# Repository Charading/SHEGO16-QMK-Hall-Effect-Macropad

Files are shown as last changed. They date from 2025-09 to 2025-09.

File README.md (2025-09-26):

# SHEGO16-QMK-Hall-Effect-Macropad
An RP2040-powered 4x4 15 key macropad with a knob on the top row, that runs custom QMK firmware that allows analogue hall effect sensors to work, also has SOCD, works with VIA and SignalRGB
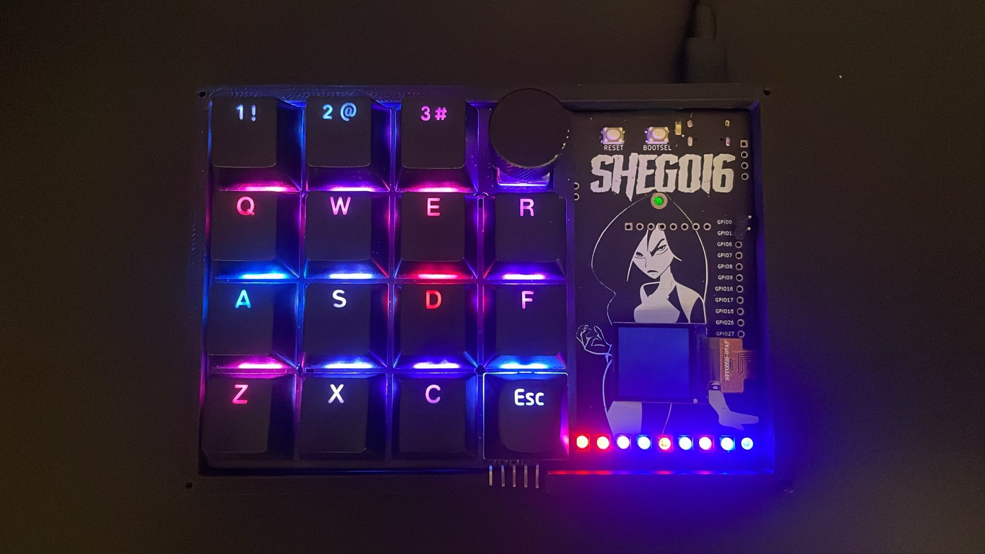
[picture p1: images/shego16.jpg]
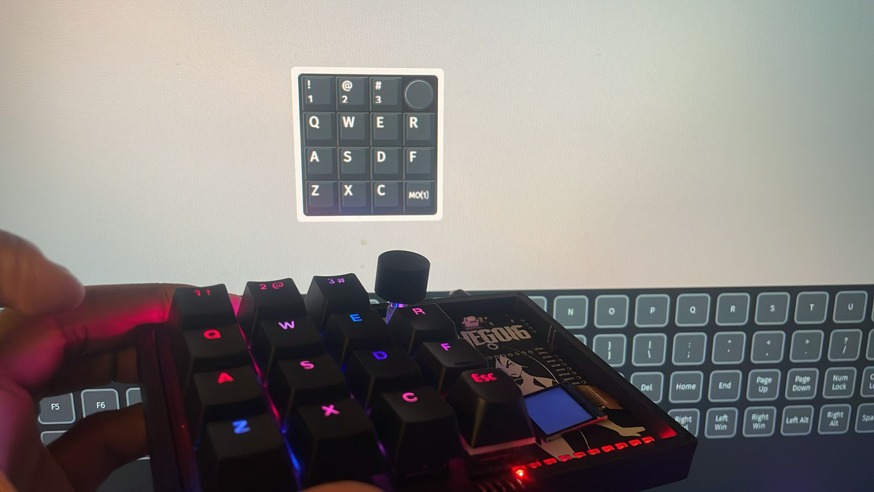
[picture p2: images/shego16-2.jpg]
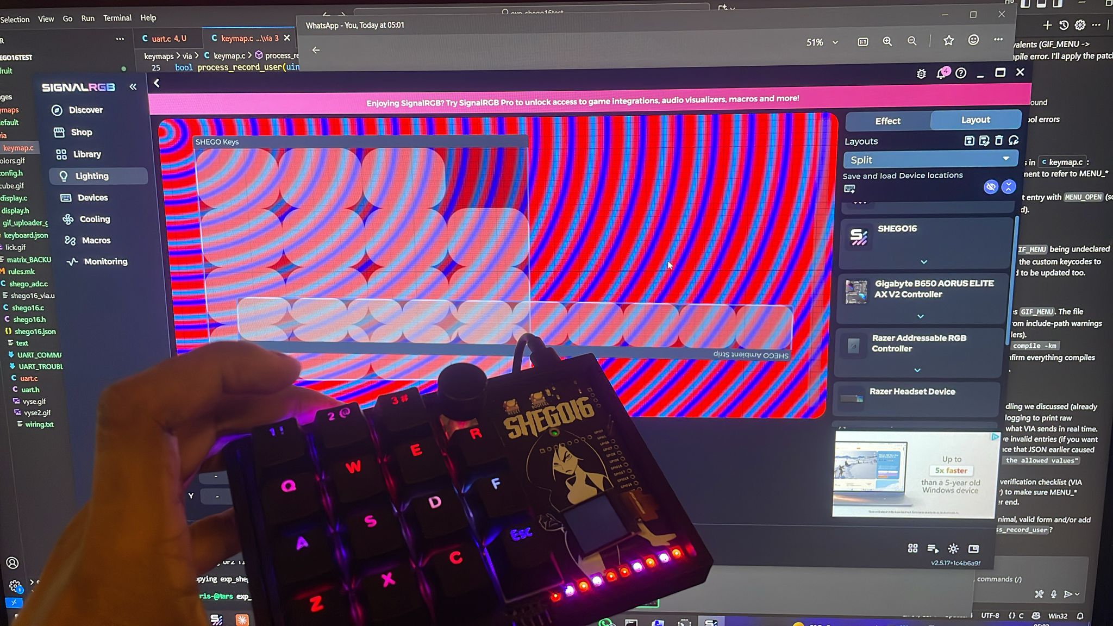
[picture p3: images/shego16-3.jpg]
  

### Features
- QMK Firmware
- VIA Compatible
- Hall effect (adjustable actuation also)
- SOCD (last input wins on A and D)
- Works with SignalRGB
- ST7735 TFT Screen *(currently disabled/broken due to complications and implementing another way)*
- Per-key RGB
- Ambient strip
- Custom keycodes to send to UART to control esp32 *(for tft screen on my future build)* etc
- Multiple GPIO broken out for testing purposes
- Blink LED on GPIO25

I cant find a Hall effect keyboard that i genuinely like that has all the features that i want so i thought to make one myself. Technically i am still in prototype phase for the 'endgame' board i yearn to have, this was a originally a little test board that I was making so I could figure out how to do firmware. I've been working months on end on this project with many pcbs and components surrounding me. The end goal is a 75% keyboard, knob, a tft screen that can play gifs, **north** facing RGB (my goodness i hate south facing), and magnetic switches with socd. Sadly I think it would be too difficult to create a software/web utility to control certain features of the board so thats why after weeks on end trying to build firmware from scratch with C, then scrapped that and tried Rust, then scrapped again and thought to use heavily edited qmk, i am now here.
For my big 75%, the screen will now be implemented by using an [ESP32 running a GIF decoder](https://github.com/Charading/ESP32-GIF-Player ) that accepts UART commands and it uses SD card for storage

Thankyou [riskable](https://github.com/riskable)  for your amazing resources and being my inspiration for this passion project. 

This was one of my first ever pcbs
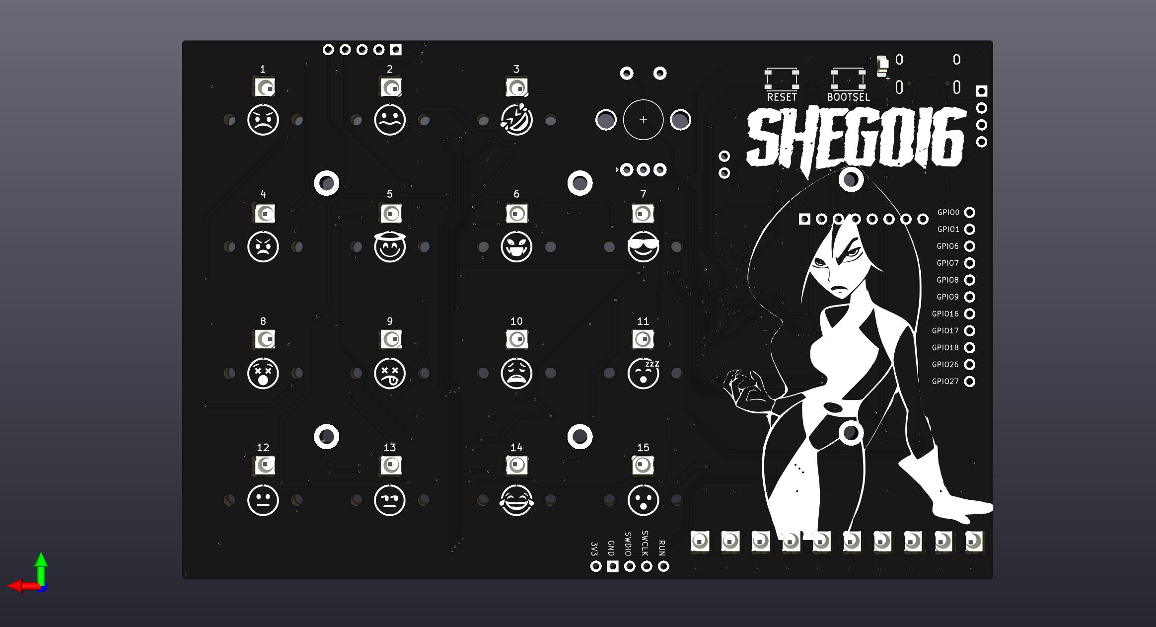
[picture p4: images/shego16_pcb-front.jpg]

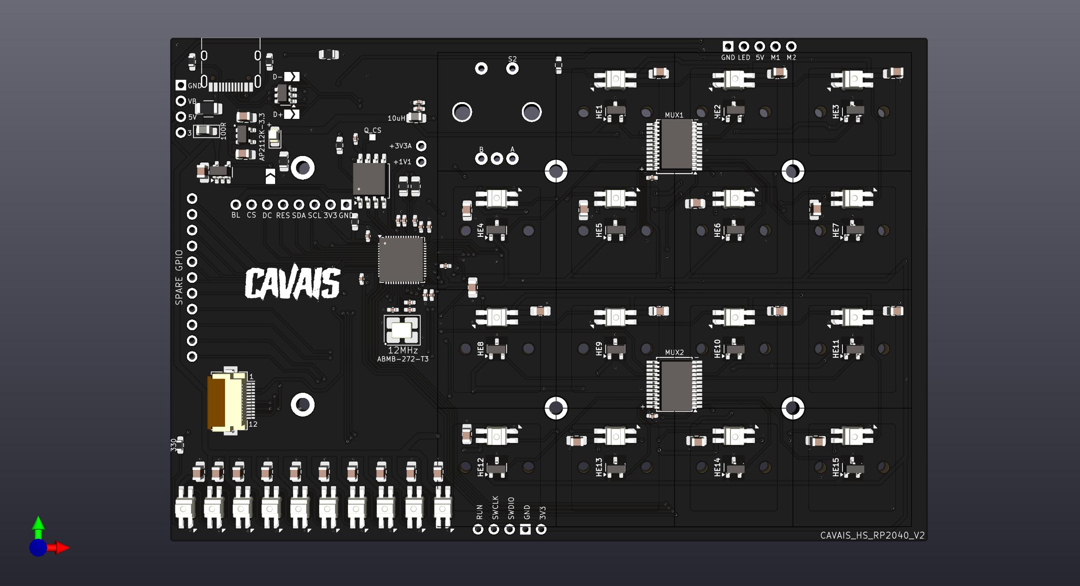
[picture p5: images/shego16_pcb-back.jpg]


I recommend using [this version](https://github.com/Charading/qmk_picosdk
) of qmk for easy building of firmware, i could not get pico/stdlib.h to be located at all with normal qmk_firmware :(.

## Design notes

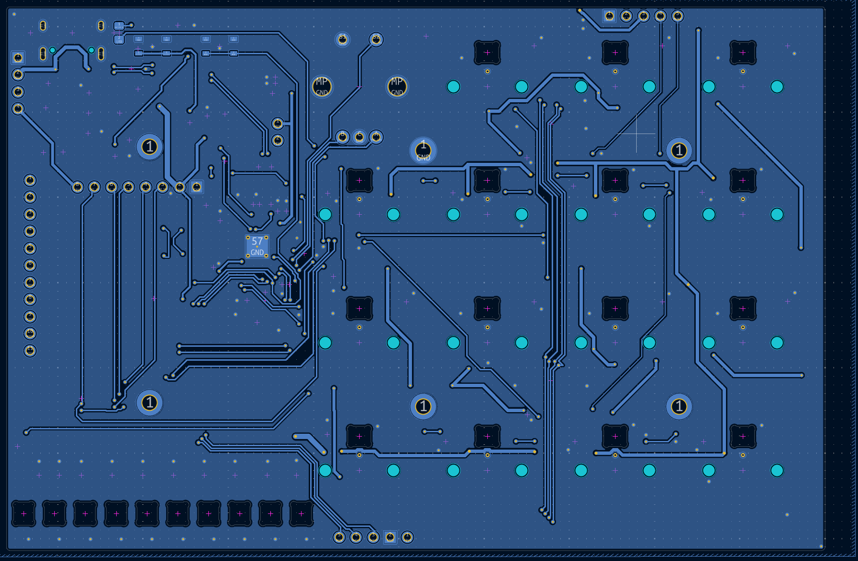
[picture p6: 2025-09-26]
images/pcb-B_Cu.png

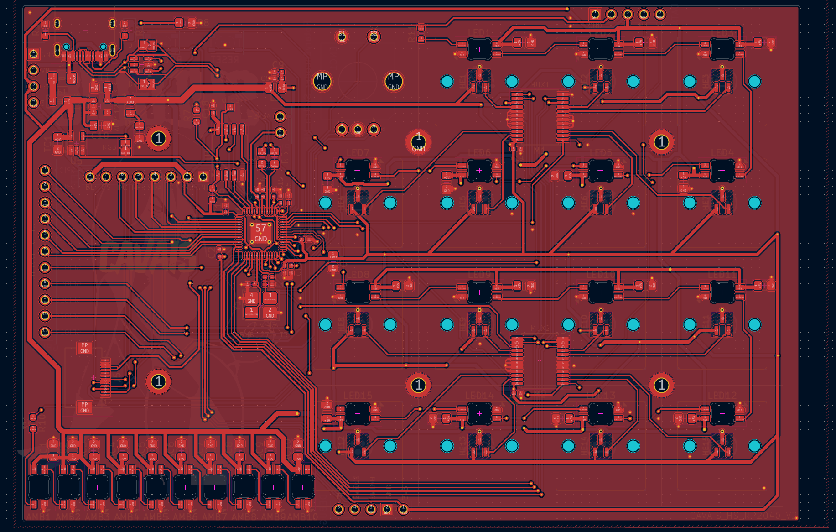
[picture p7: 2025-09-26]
images/pcb-F_Cu.png

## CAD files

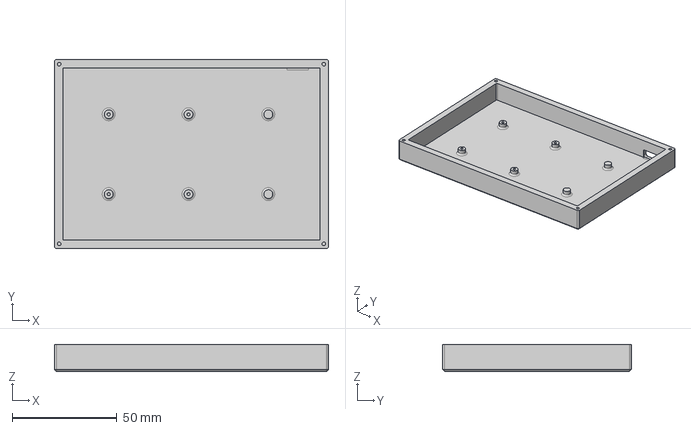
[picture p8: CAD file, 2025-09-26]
shego16-kicad/Cav16 Case v11.step
130.8 x 90.2 x 13.0 mm

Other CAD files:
shego16-kicad/Cav16 Case v9.step

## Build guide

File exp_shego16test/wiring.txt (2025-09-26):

//SPI control pins
#define SPI_SCL GP2
#define SPI_SDA GP3
#define SPI_RES GP4
#define SPI_DC GP5
#define SPI_CS GP24

// MUX control pins
#define MUX_S0 GP10
#define MUX_S1 GP11
#define MUX_S2 GP12
#define MUX_S3 GP13

// MUX enable pins (active low)
#define MUX1_EN GP14
#define MUX2_EN GP15

// ADC pins for reading mux outputs
#define MUX1_ADC_PIN GP29
#define MUX2_ADC_PIN GP28

// Hall effect threshold
#define HALL_THRESHOLD 350

// Mux to sensor wiring, every unused channel is GND. Mux is HC4067, sensors are SS49E.
/*
MUX1 
i0 he2
i1 he3
i6 he7
i7 he6
i8 he5
i9 he4
i15 he1

MUX2
i0 he10
i1 he11
i6 he15
i7 he14
i8 he13
i9 he12
i14 he8
i15 he9
*/

const uint16_t key_thresholds[32] = {
    // MUX1 thresholds
    380, 360, 0, 0, 0, 0, 375, 380, 399, 399, 0, 0, 0, 0, 0, 380,  // E key (ch8) gets 320
    // MUX2 thresholds  
    340, 400, 0, 0, 0, 0, 330, 390, 380, 410, 0, 0, 0, 0, 366, 460
};

Okay, so, is there a way to instead of using a static threshold, to make it so the keyboard scans all adc keys when plugged in, and then it only does a key press when the value deviates up OR down 20% away

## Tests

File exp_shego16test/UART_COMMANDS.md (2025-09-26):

# UART Commands Implementation for Shego16test

This document explains the custom UART functionality added to the Shego16test keyboard for communicating with an ESP32 to control GIF playback.

## Overview

The keyboard now has custom keycodes on Layer 3 that send UART commands to an ESP32. The ESP32 can respond to these commands to control a GIF player interface.

## Hardware Configuration

### Wiring
- **QMK Side (RP2040)**: 
  - TX: GP1 → ESP32 RX pin
  - GND: Connect GND between boards

**Note**: Using GP1 for UART TX to avoid conflicts with RGB matrix pins and other peripherals.

### UART Settings
- **Baud Rate**: 115200
- **Data Bits**: 8
- **Stop Bits**: 1
- **Parity**: None

## Layer Layout

### Layer 3 - UART Commands
```
┌─────────┬─────────┬─────────┬───┐
│GIF_MENU │ GIF_UP  │GIF_DOWN │ENC│
├─────────┼─────────┼─────────┼───┤
│GIF_SELECT│  ---   │   ---   │---│
├─────────┼─────────┼─────────┼───┤
│   ---   │   ---   │   ---   │---│
├─────────┼─────────┼─────────┼───┤
│   ---   │   ---   │   ---   │---│
└─────────┴─────────┴─────────┴───┘
```

## Custom Keycodes

| Keycode | UART Command Sent | Description |
|---|---|---|
| `GIF_MENU` | `MENU_OPEN\n` | Opens/toggles the GIF selection menu |
| `GIF_UP` | `MENU_UP\n` | Navigate up in menu |
| `GIF_DOWN` | `MENU_DOWN\n` | Navigate down in menu |
| `GIF_SELECT` | `MENU_SELECT\n` | Select current GIF |

## Layer Access

To access Layer 3 (UART commands):
- **From Layer 0**: Hold the bottom-right key (was KC_V, now MO(3))
- **From Layer 1**: Hold the bottom-right key (MO(3))

## ESP32 Expected Responses

According to the documentation provided, the ESP32 should send back these responses:

### Status Messages
- `MENU_OPENED` / `MENU_CLOSED` - Menu state changes
- `MENU_POS:3` - Current menu position (number)
- `GIF_SELECTED:filename.gif` - Selected GIF file
- `STATUS:MENU=OPEN,GIF=vyse.gif,POS=2,COUNT=4` - Full status
- `UNKNOWN_COMMAND` - For invalid commands

### How to Test

1. **Build and flash** the firmware to your RP2040
2. **Connect UART wires** between RP2040 and ESP32 as specified
3. **Access Layer 3** by holding the bottom-right key
4. **Press the UART command keys** and monitor the ESP32's serial output
5. **Verify** that the ESP32 receives the expected commands

## Code Files Modified

- `config.h` - Added UART pin definitions
- `rules.mk` - Enabled UART feature
- `keymaps/default/keymap.c` - Added custom keycodes and UART command handling

## Troubleshooting

### No UART Communication
1. Check wiring (TX/RX crossed correctly)
2. Verify baud rate matches on both sides (115200)
3. Ensure GND is connected between boards

### Commands Not Recognized
1. Check that ESP32 code is properly handling the command strings
2. Verify newline characters are being sent (`\n`)
3. Monitor ESP32 serial output for debugging

### Layer 3 Not Accessible
1. Confirm you're holding (not tapping) the MO(3) key
2. Check that the keymap compiled correctly
3. Verify layer switching is working with other layers first

## Future Enhancements

Consider adding:
- Status LED indicators based on ESP32 responses
- Additional UART commands (volume, play/pause, etc.)
- Two-way communication to display ESP32 status on keyboard
- Error handling for failed UART communication

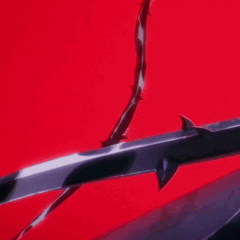
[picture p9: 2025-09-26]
exp_shego16test/vyse2.gif

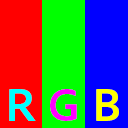
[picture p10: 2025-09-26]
exp_shego16test/colors.gif

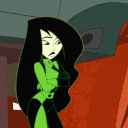
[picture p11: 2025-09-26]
exp_shego16test/gif/init.gif

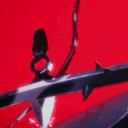
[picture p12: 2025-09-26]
exp_shego16test/vyse.gif

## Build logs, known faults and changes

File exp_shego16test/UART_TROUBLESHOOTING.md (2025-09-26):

# UART Troubleshooting Summary - Shego16test

## What We Implemented
- Custom bit-banged UART implementation on GP1
- UART commands for GIF control (MENU_OPEN, MENU_UP, MENU_DOWN, MENU_SELECT)
- Encoder-based UART controls on Layer 3
- LED feedback to confirm key presses
- Startup test message
- Multiple baud rates tested (115200 and 9600)

## Issues Encountered
- No UART output detected on receiving device
- Custom keycodes trigger (LED feedback works) but UART transmission fails

## Possible Causes
1. **Hardware Issues:**
   - GP1 pin might not be properly connected
   - Voltage level mismatch (3.3V RP2040 vs 5V/different voltage ESP32)
   - Missing ground connection between boards
   - Wrong ESP32 RX pin configuration

2. **Software Issues:**
   - QMK's `wait_us()` function might not be precise enough for bit-banging
   - Interrupt conflicts during transmission
   - Pin configuration conflicts

3. **Timing Issues:**
   - Bit-banged UART timing might be off due to QMK overhead
   - ESP32 might expect different baud rate or timing

## Alternative Approaches to Try Later

### 1. Use QMK's Built-in Serial Driver
```c
// In config.h
#define SERIAL_USART_DRIVER SD1
#define SERIAL_USART_TX_PIN GP0

// In rules.mk
SERIAL_DRIVER = vendor
```

### 2. Use Raw HID Instead of UART
- Send commands via USB HID to host computer
- Host computer forwards to ESP32 via its own UART/USB
- More reliable than bit-banged UART

### 3. Hardware UART (if available)
- Use RP2040's hardware UART peripheral instead of bit-banging
- More precise timing and less CPU overhead

### 4. Different Pin/Voltage Level
- Try different GPIO pin (GP0, GP4, GP8, etc.)
- Add level shifter if voltage mismatch
- Verify ESP32 RX pin with multimeter/oscilloscope

### 5. I2C Communication
- Use I2C protocol instead of UART
- More robust for short-distance communication
- Built-in error checking

## Hardware Debugging Steps
1. **Verify pin output with multimeter:**
   - Check if GP1 goes high/low during transmission
   - Confirm 3.3V levels

2. **Test with simple LED:**
   - Connect LED to GP1 to visually confirm pin toggling
   - Should blink during UART transmission

3. **Check connections:**
   - Verify GP1 → ESP32 RX
   - Verify GND → GND
   - Check for loose connections

## Code Cleanup
If you want to remove UART functionality for now, remove these sections:
- Custom keycodes (GIF_MENU, GIF_UP, GIF_DOWN, GIF_SELECT)
- UART functions (uart_send_byte, uart_send_string)
- UART initialization in keyboard_post_init_user
- UART handling in encoder_update_user and process_record_user

## Current Status
- VIA keymap compiles successfully
- Custom keycodes trigger with LED feedback
- UART transmission implemented but not working
- Ambient LED functionality preserved and working

The implementation is solid from a software perspective - the issue is likely hardware-related or requires a different communication approach.

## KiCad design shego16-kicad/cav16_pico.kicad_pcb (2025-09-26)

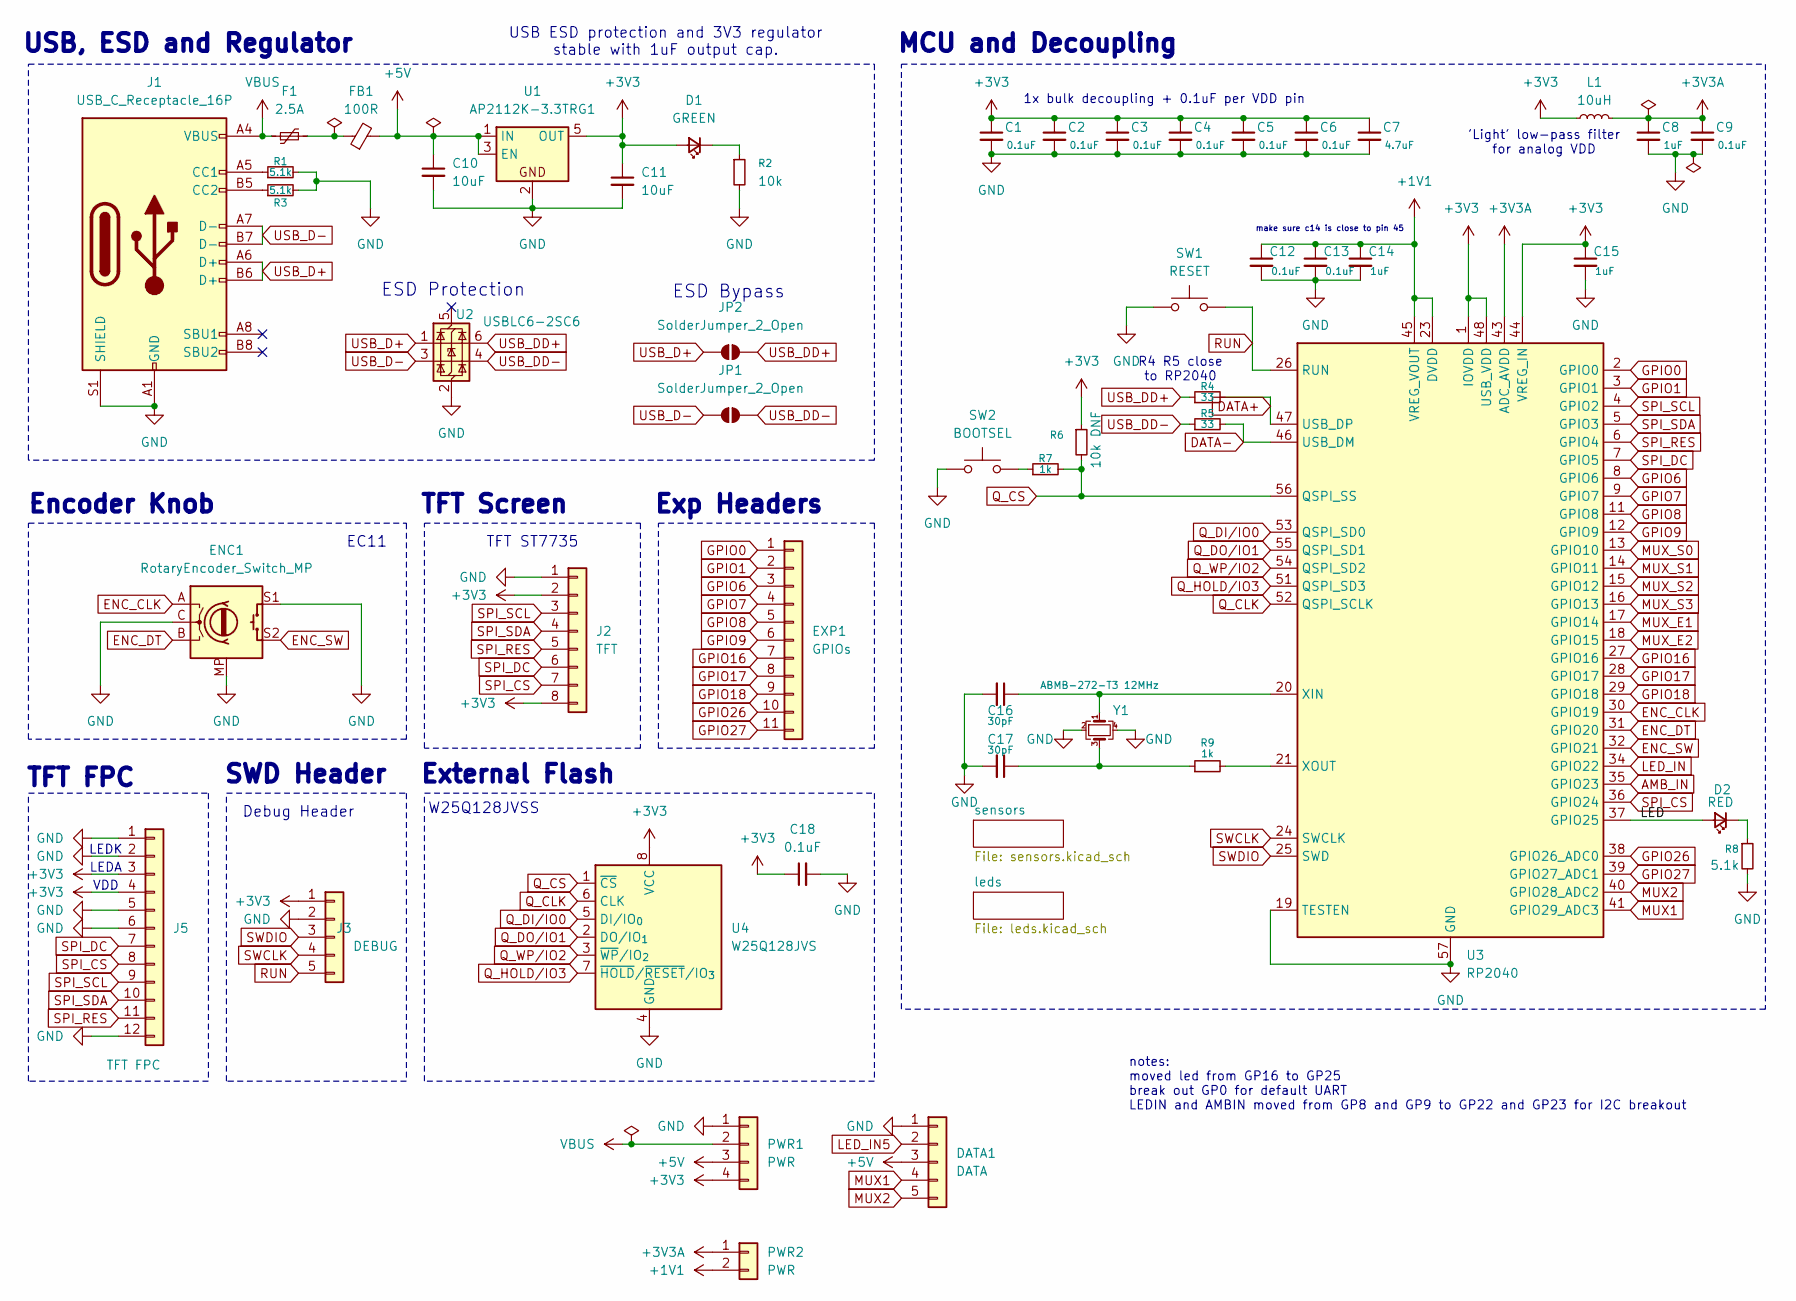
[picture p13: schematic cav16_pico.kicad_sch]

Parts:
C1, C2, C3, C4, C5, C6, C9, C12, C13, C18: 0.1uF; C_0402_1005Metric_Pad0.74x0.62mm_HandSolder
C7: 4.7uF; C_0805_2012Metric_Pad1.18x1.45mm_HandSolder
C8, C14, C15: 1uF; C_0402_1005Metric_Pad0.74x0.62mm_HandSolder
C10, C11: 10uF; C_0805_2012Metric_Pad1.18x1.45mm_HandSolder
C16, C17: 30pF; C_0402_1005Metric_Pad0.74x0.62mm_HandSolder
D1: GREEN; LED_0805_2012Metric_Pad1.15x1.40mm_HandSolder
D2: RED; LED_0805_2012Metric_Pad1.15x1.40mm_HandSolder
DATA1: DATA; PinHeader_1x05_P2.54mm_Vertical
ENC1: RotaryEncoder_Switch_MP; RotaryEncoder_Alps_EC11E-Switch_Vertical_H20mm_CircularMoun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
EXP1: GPIOs; PinHeader_1x11_P2.54mm_Vertical
F1: 2.5A; Fuse_1206_3216Metric_Pad1.42x1.75mm_BigPads
FB1: 100R; Ferrite_0805_2012Metric_Pad1.05x1.20mm_BigPads
J1: USB_C_Receptacle_16P; USB_C_Receptacle_HRO_TYPE-C-31-M-12
J2: TFT; PinHeader_1x08_P2.54mm_Vertical
J3: DEBUG; PinHeader_1x05_P2.54mm_Vertical
J5: TFT FPC; Hirose_FH12-12S-0.5SH_1x12-1MP_P0.50mm_Horizontal
JP1, JP2: SolderJumper_2_Open; SolderJumper-2_P1.3mm_Open_TrianglePad1.0x1.5mm
L1: 10uH; L_0805_2012Metric_Pad1.15x1.40mm_HandSolder
PWR1: PWR; PinHeader_1x04_P2.54mm_Vertical
PWR2: PWR; PinHeader_1x02_P2.54mm_Vertical
R1, R3: 5.1k; R_0603_1608Metric_Pad0.98x0.95mm_HandSolder
R2: 10k; R_0805_2012Metric_Pad1.20x1.40mm_HandSolder
R4, R5: 33; R_0805_2012Metric_Pad1.20x1.40mm_HandSolder
R6: 10k DNF; R_0603_1608Metric_Pad0.98x0.95mm_HandSolder
R7: 1k; R_0603_1608Metric_Pad0.98x0.95mm_HandSolder
R8: 5.1k; R_0805_2012Metric_Pad1.20x1.40mm_HandSolder
R9: 1k; C_0402_1005Metric_Pad0.74x0.62mm_HandSolder
SW1: RESET; SW_SPST_PTS810
SW2: BOOTSEL; SW_SPST_PTS810
U1: AP2112K-3.3TRG1; SOT-23-5
U2: USBLC6-2SC6; SOT-23-6
U3: RP2040; QFN-56-1EP_7x7mm_P0.4mm_EP3.2x3.2mm_ThermalVias
U4: W25Q128JVS; SOIC-8_5.3x5.3mm_P1.27mm
Y1: ABMB-272-T3 12MHz; Crystal_SMD_3225-4Pin_3.2x2.5mm_BigPads

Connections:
+1V1: C12.1, C13.1, C14.1, PWR2.2, U3.23 (DVDD), U3.45 (VREG_VOUT), U3.50 (DVDD)
+3V3: C1.1, C2.1, C3.1, C4.1, C5.1, C6.1, C7.1, C11.1, C15.1, C18.1, D1.2 (A), J2.2, J2.8, J3.1, J5.3, J5.4, L1.1, PWR1.4, R6.1, U1.5 (OUT), U3.1 (IOVDD), U3.10 (IOVDD), U3.22 (IOVDD), U3.33 (IOVDD), U3.42 (IOVDD), U3.44 (VREG_IN), U3.48 (USB_VDD), U3.49 (IOVDD), U4.8 (VCC); also elsewhere on the board
+3V3A: C8.1, C9.1, L1.2, PWR2.1, U3.43 (ADC_AVDD)
+5V: C10.1, DATA1.3, FB1.2, PWR1.3, U1.1 (IN), U1.3 (EN); also elsewhere on the board
/LED: D2.2 (A), U3.37 (GPIO25)
AMB_IN: U3.35 (GPIO23); also elsewhere on the board
DATA+: R4.2, U3.47 (USB_DP)
DATA-: R5.2, U3.46 (USB_DM)
ENC_CLK: ENC1.A, U3.30 (GPIO19)
ENC_DT: ENC1.B, U3.31 (GPIO20)
ENC_SW: ENC1.S2, U3.32 (GPIO21)
GND: C1.2, C2.2, C3.2, C4.2, C5.2, C6.2, C7.2, C8.2, C9.2, C10.2, C11.2, C12.2, C13.2, C14.2, C15.2, C16.2, C17.2, C18.2, DATA1.1, ENC1.C, ENC1.MP, ENC1.S1, J1.A1 (GND), J1.A12 (GND), J1.B1 (GND), J1.B12 (GND), J1.S1 (SHIELD), J2.1, J3.2, J5.1, J5.2, J5.5, J5.6, J5.12, J5.MP, PWR1.1, R1.2, R2.2, R3.2, R8.2, SW1.1, SW2.1, U1.2, U2.2 (GND), U3.19 (TESTEN), U3.57 (GND), U4.4 (GND), Y1.2, Y1.4; also elsewhere on the board
GPIO0: EXP1.1, U3.2 (GPIO0)
GPIO1: EXP1.2, U3.3 (GPIO1)
GPIO6: EXP1.3, U3.8 (GPIO6)
GPIO7: EXP1.4, U3.9 (GPIO7)
GPIO8: EXP1.5, U3.11 (GPIO8)
GPIO9: EXP1.6, U3.12 (GPIO9)
GPIO16: EXP1.7, U3.27 (GPIO16)
GPIO17: EXP1.8, U3.28 (GPIO17)
GPIO18: EXP1.9, U3.29 (GPIO18)
GPIO26: EXP1.10, U3.38 (GPIO26_ADC0)
GPIO27: EXP1.11, U3.39 (GPIO27_ADC1)
LED_IN: U3.34 (GPIO22); also elsewhere on the board
LED_IN5: DATA1.2; also elsewhere on the board
MUX1: DATA1.4, U3.41 (GPIO29_ADC3); also elsewhere on the board
MUX2: DATA1.5, U3.40 (GPIO28_ADC2); also elsewhere on the board
MUX_E1: U3.17 (GPIO14); also elsewhere on the board
MUX_E2: U3.18 (GPIO15); also elsewhere on the board
MUX_S0: U3.13 (GPIO10); also elsewhere on the board
MUX_S1: U3.14 (GPIO11); also elsewhere on the board
MUX_S2: U3.15 (GPIO12); also elsewhere on the board
MUX_S3: U3.16 (GPIO13); also elsewhere on the board
unnamed: C17.1, R9.1, Y1.3
unnamed: D1.1 (K), R2.1
unnamed: D2.1 (K), R8.1
unnamed: F1.2, FB1.1
unnamed: J1.A5 (CC1), R1.1
unnamed: J1.B5 (CC2), R3.1
unnamed: R7.1, SW2.2
unnamed: C16.1, U3.20 (XIN), Y1.1
unnamed: R9.2, U3.21 (XOUT)
Q_CLK: U3.52 (QSPI_SCLK), U4.6 (CLK)
Q_CS: R6.2, R7.2, U3.56 (QSPI_SS), U4.1 (~CS)
Q_DI/IO0: U3.53 (QSPI_SD0), U4.5 (DI/IO_{0})
Q_DO/IO1: U3.55 (QSPI_SD1), U4.2 (DO/IO_{1})
Q_HOLD/IO3: U3.51 (QSPI_SD3), U4.7 (~HOLD/~RESET/IO_{3})
Q_WP/IO2: U3.54 (QSPI_SD2), U4.3 (~WP/IO_{2})
RUN: J3.5, SW1.2, U3.26 (RUN)
SPI_CS: J2.7, J5.8, U3.36 (GPIO24)
SPI_DC: J2.6, J5.7, U3.7 (GPIO5)
SPI_RES: J2.5, J5.11, U3.6 (GPIO4)
SPI_SCL: J2.3, J5.9, U3.4 (GPIO2)
SPI_SDA: J2.4, J5.10, U3.5 (GPIO3)
SWCLK: J3.4, U3.24 (SWCLK)
SWDIO: J3.3, U3.25 (SWD)
USB_D+: J1.A6 (D+), J1.B6 (D+), JP2.1 (A), U2.1 (I/O1)
USB_D-: J1.A7 (D-), J1.B7 (D-), JP1.1 (A), U2.3 (I/O2)
USB_DD+: JP2.2 (B), R4.1, U2.6 (I/O1)
USB_DD-: JP1.2 (B), R5.1, U2.4 (I/O2)
VBUS: F1.1, J1.A4 (VBUS), J1.A9 (VBUS), J1.B4 (VBUS), J1.B9 (VBUS), PWR1.2

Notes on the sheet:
TFT Screen
LEDA
R4 R5 close to RP2040
notes: moved led from GP16 to GP25 break out GP0 for default UART LEDIN and AMBIN moved from GP8 and GP9 to GP22 and GP23 for I2C breakout
Encoder Knob
MCU and Decoupling
LEDK
External Flash
USB, ESD and Regulator
ESD Bypass
SWD Header
make sure c14 is close to pin 45
'Light' low-pass filter for analog VDD
Debug Header
VDD
Exp Headers
EC11
1x bulk decoupling + 0.1uF per VDD pin
TFT FPC
ESD Protection
USB ESD protection and 3V3 regulator stable with 1uF output cap.
TFT ST7735
W25Q128JVSS

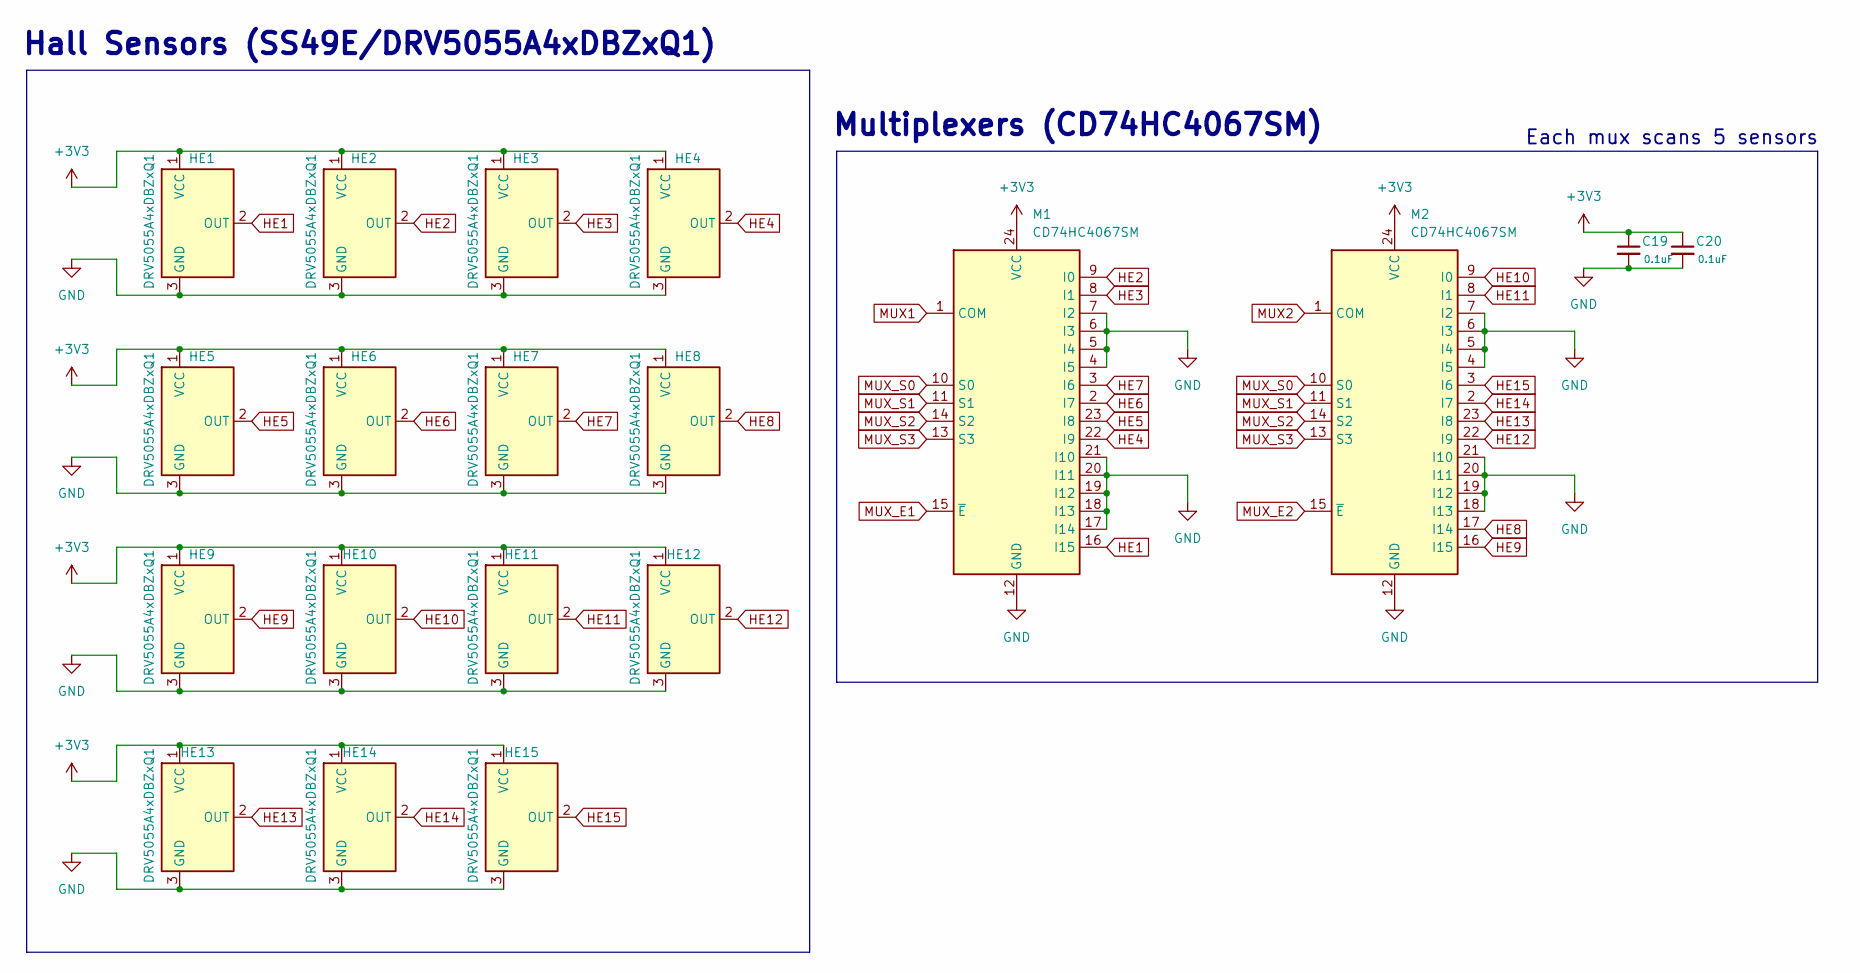
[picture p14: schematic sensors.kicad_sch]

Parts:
C19, C20: 0.1uF; C_0402_1005Metric_Pad0.74x0.62mm_HandSolder
HE1, HE2, HE3, HE4, HE5, HE6, HE7, HE8, HE9, HE10, HE11, HE12, HE13, HE14, HE15: DRV5055A4xDBZxQ1; SW_MX_HE_90deg_1u
M1, M2: CD74HC4067SM; SSOP-24_5.3x8.2mm_P0.65mm

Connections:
+3V3: C19.1, C20.1, HE1.1 (VCC), HE2.1 (VCC), HE3.1 (VCC), HE4.1 (VCC), HE5.1 (VCC), HE6.1 (VCC), HE7.1 (VCC), HE8.1 (VCC), HE9.1 (VCC), HE10.1 (VCC), HE11.1 (VCC), HE12.1 (VCC), HE13.1 (VCC), HE14.1 (VCC), HE15.1 (VCC), M1.24 (VCC), M2.24 (VCC); also elsewhere on the board
GND: C19.2, C20.2, HE1.3 (GND), HE2.3 (GND), HE3.3 (GND), HE4.3 (GND), HE5.3 (GND), HE6.3 (GND), HE7.3 (GND), HE8.3 (GND), HE9.3 (GND), HE10.3 (GND), HE11.3 (GND), HE12.3 (GND), HE13.3 (GND), HE14.3 (GND), HE15.3 (GND), M1.4 (I5), M1.5 (I4), M1.6 (I3), M1.7 (I2), M1.12 (GND), M1.17 (I14), M1.18 (I13), M1.19 (I12), M1.20 (I11), M1.21 (I10), M2.4 (I5), M2.5 (I4), M2.6 (I3), M2.7 (I2), M2.12 (GND), M2.18 (I13), M2.19 (I12), M2.20 (I11), M2.21 (I10); also elsewhere on the board
HE1: HE1.2 (OUT), M1.16 (I15)
HE2: HE2.2 (OUT), M1.9 (I0)
HE3: HE3.2 (OUT), M1.8 (I1)
HE4: HE4.2 (OUT), M1.22 (I9)
HE5: HE5.2 (OUT), M1.23 (I8)
HE6: HE6.2 (OUT), M1.2 (I7)
HE7: HE7.2 (OUT), M1.3 (I6)
HE8: HE8.2 (OUT), M2.17 (I14)
HE9: HE9.2 (OUT), M2.16 (I15)
HE10: HE10.2 (OUT), M2.9 (I0)
HE11: HE11.2 (OUT), M2.8 (I1)
HE12: HE12.2 (OUT), M2.22 (I9)
HE13: HE13.2 (OUT), M2.23 (I8)
HE14: HE14.2 (OUT), M2.2 (I7)
HE15: HE15.2 (OUT), M2.3 (I6)
MUX1: M1.1 (COM); also elsewhere on the board
MUX2: M2.1 (COM); also elsewhere on the board
MUX_E1: M1.15 (~E); also elsewhere on the board
MUX_E2: M2.15 (~E); also elsewhere on the board
MUX_S0: M1.10 (S0), M2.10 (S0); also elsewhere on the board
MUX_S1: M1.11 (S1), M2.11 (S1); also elsewhere on the board
MUX_S2: M1.14 (S2), M2.14 (S2); also elsewhere on the board
MUX_S3: M1.13 (S3), M2.13 (S3); also elsewhere on the board

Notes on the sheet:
Each mux scans 5 sensors
Multiplexers (CD74HC4067SM)
Hall Sensors (SS49E/DRV5055A4xDBZxQ1)

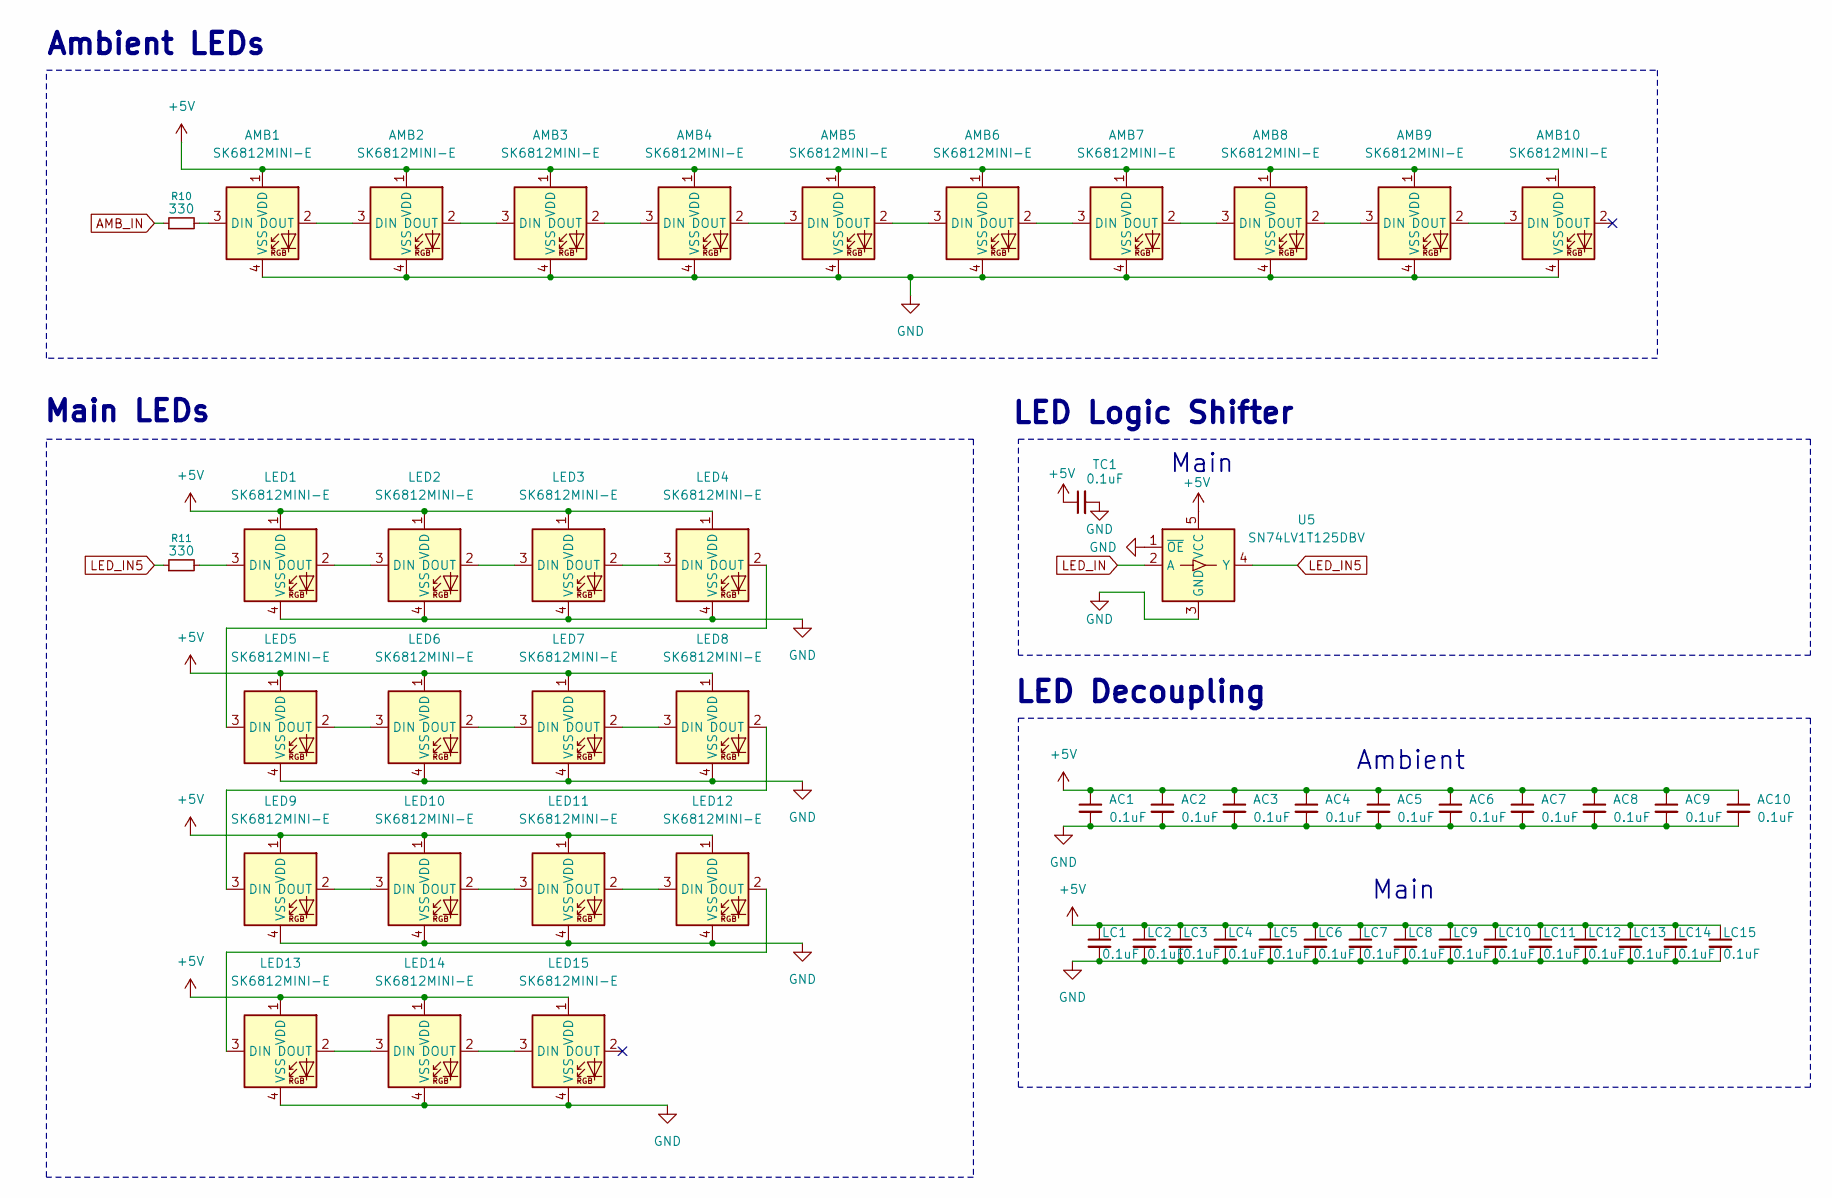
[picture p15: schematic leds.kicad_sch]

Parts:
AC1, AC2, AC3, AC4, AC5, AC6, AC7, AC8, AC9, AC10: 0.1uF; C_0805_2012Metric_Pad1.18x1.45mm_HandSolder
AMB1, AMB2, AMB3, AMB4, AMB5, AMB6, AMB7, AMB8, AMB9, AMB10: SK6812MINI-E; LED_6028R
LC1, LC2, LC3, LC4, LC5, LC6, LC7, LC8, LC9, LC10, LC11, LC12, LC13, LC14, LC15: 0.1uF; C_0805_2012Metric_Pad1.18x1.45mm_HandSolder
LED1, LED2, LED3, LED4, LED5, LED6, LED7, LED8, LED9, LED10, LED11, LED12, LED13, LED14, LED15: SK6812MINI-E; LED_6028R
R10, R11: 330; R_0603_1608Metric_Pad0.98x0.95mm_HandSolder
TC1: 0.1uF; C_0805_2012Metric_Pad1.18x1.45mm_HandSolder
U5: SN74LV1T125DBV; SOT-23-5

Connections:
+5V: AC1.1, AC2.1, AC3.1, AC4.1, AC5.1, AC6.1, AC7.1, AC8.1, AC9.1, AC10.1, AMB1.1 (VDD), AMB2.1 (VDD), AMB3.1 (VDD), AMB4.1 (VDD), AMB5.1 (VDD), AMB6.1 (VDD), AMB7.1 (VDD), AMB8.1 (VDD), AMB9.1 (VDD), AMB10.1 (VDD), LC1.1, LC2.1, LC3.1, LC4.1, LC5.1, LC6.1, LC7.1, LC8.1, LC9.1, LC10.1, LC11.1, LC12.1, LC13.1, LC14.1, LC15.1, LED1.1 (VDD), LED2.1 (VDD), LED3.1 (VDD), LED4.1 (VDD), LED5.1 (VDD), LED6.1 (VDD), LED7.1 (VDD), LED8.1 (VDD), LED9.1 (VDD), LED10.1 (VDD), LED11.1 (VDD), LED12.1 (VDD), LED13.1 (VDD), LED14.1 (VDD), LED15.1 (VDD), TC1.1, U5.5 (VCC); also elsewhere on the board
AMB_IN: R10.1; also elsewhere on the board
GND: AC1.2, AC2.2, AC3.2, AC4.2, AC5.2, AC6.2, AC7.2, AC8.2, AC9.2, AC10.2, AMB1.4 (VSS), AMB2.4 (VSS), AMB3.4 (VSS), AMB4.4 (VSS), AMB5.4 (VSS), AMB6.4 (VSS), AMB7.4 (VSS), AMB8.4 (VSS), AMB9.4 (VSS), AMB10.4 (VSS), LC1.2, LC2.2, LC3.2, LC4.2, LC5.2, LC6.2, LC7.2, LC8.2, LC9.2, LC10.2, LC11.2, LC12.2, LC13.2, LC14.2, LC15.2, LED1.4 (VSS), LED2.4 (VSS), LED3.4 (VSS), LED4.4 (VSS), LED5.4 (VSS), LED6.4 (VSS), LED7.4 (VSS), LED8.4 (VSS), LED9.4 (VSS), LED10.4 (VSS), LED11.4 (VSS), LED12.4 (VSS), LED13.4 (VSS), LED14.4 (VSS), LED15.4 (VSS), TC1.2, U5.1 (~OE), U5.3 (GND); also elsewhere on the board
LED_IN: U5.2 (A); also elsewhere on the board
LED_IN5: R11.1, U5.4 (Y); also elsewhere on the board
unnamed: AMB1.3 (DIN), R10.2
unnamed: AMB1.2 (DOUT), AMB2.3 (DIN)
unnamed: AMB2.2 (DOUT), AMB3.3 (DIN)
unnamed: AMB3.2 (DOUT), AMB4.3 (DIN)
unnamed: AMB4.2 (DOUT), AMB5.3 (DIN)
unnamed: AMB5.2 (DOUT), AMB6.3 (DIN)
unnamed: AMB6.2 (DOUT), AMB7.3 (DIN)
unnamed: AMB7.2 (DOUT), AMB8.3 (DIN)
unnamed: AMB8.2 (DOUT), AMB9.3 (DIN)
unnamed: AMB9.2 (DOUT), AMB10.3 (DIN)
unnamed: LED1.3 (DIN), R11.2
unnamed: LED1.2 (DOUT), LED2.3 (DIN)
unnamed: LED2.2 (DOUT), LED3.3 (DIN)
unnamed: LED3.2 (DOUT), LED4.3 (DIN)
unnamed: LED4.2 (DOUT), LED5.3 (DIN)
unnamed: LED5.2 (DOUT), LED6.3 (DIN)
unnamed: LED6.2 (DOUT), LED7.3 (DIN)
unnamed: LED7.2 (DOUT), LED8.3 (DIN)
unnamed: LED8.2 (DOUT), LED9.3 (DIN)
unnamed: LED9.2 (DOUT), LED10.3 (DIN)
unnamed: LED10.2 (DOUT), LED11.3 (DIN)
unnamed: LED11.2 (DOUT), LED12.3 (DIN)
unnamed: LED12.2 (DOUT), LED13.3 (DIN)
unnamed: LED13.2 (DOUT), LED14.3 (DIN)
unnamed: LED14.2 (DOUT), LED15.3 (DIN)

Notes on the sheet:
Main
Ambient LEDs
Main LEDs
Ambient
LED Logic Shifter
LED Decoupling

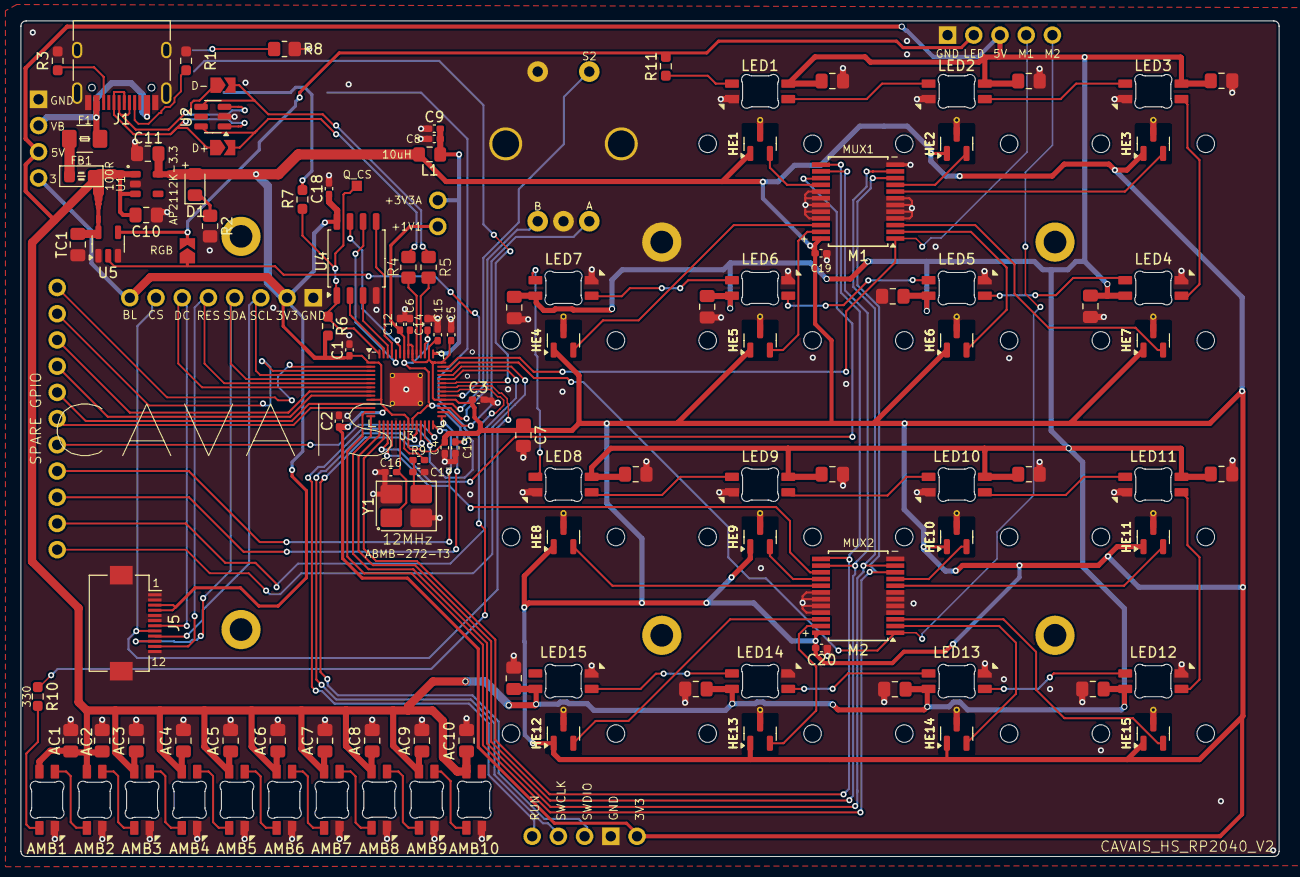
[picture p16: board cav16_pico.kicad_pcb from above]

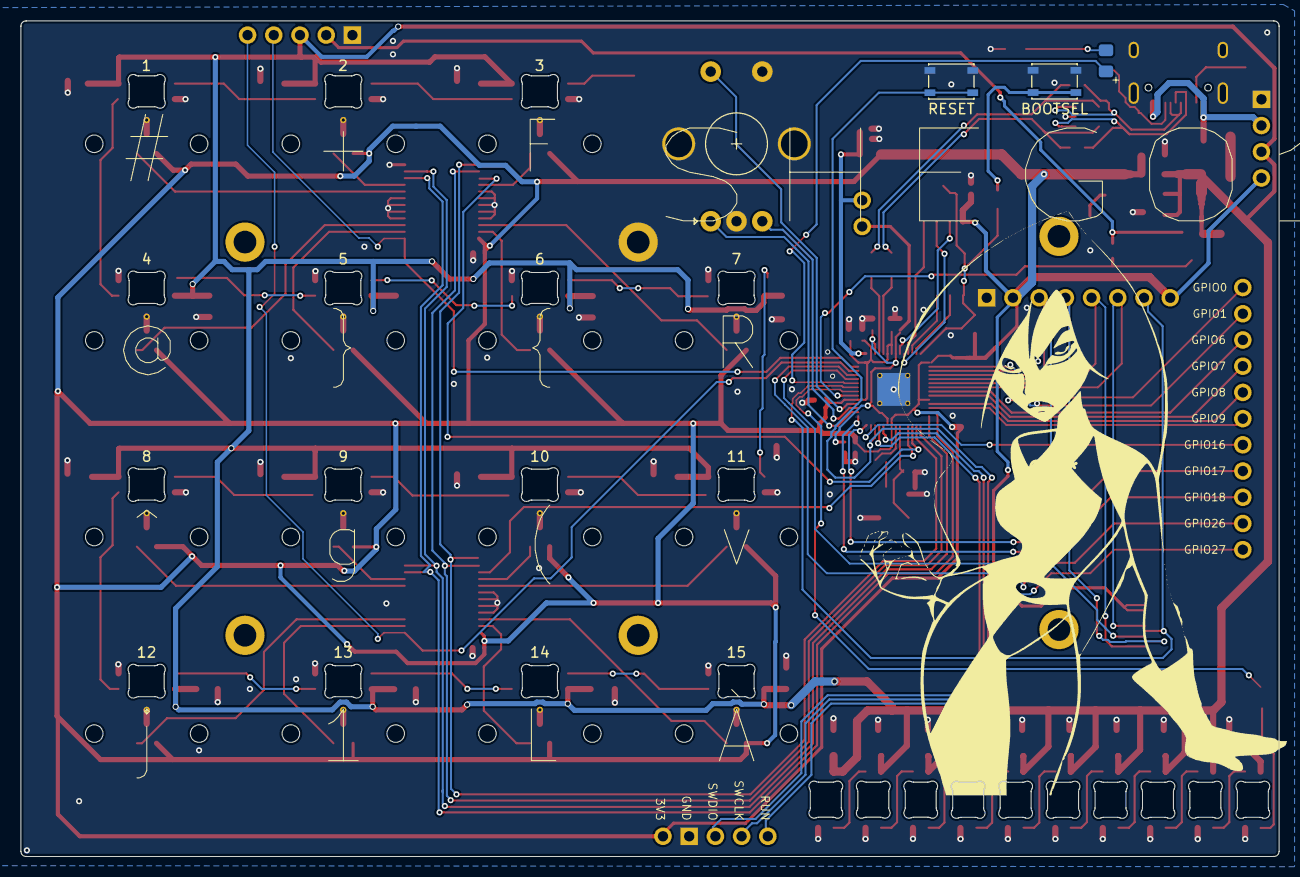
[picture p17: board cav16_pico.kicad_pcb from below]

Board: 2 copper layers, 121.9 x 81.0 mm, 124 parts (10 on the bottom side), 101 nets.

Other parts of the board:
RGB: SolderJumper-2_P1.3mm_Open_TrianglePad1.0x1.5mm

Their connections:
LED_IN: RGB.1; also elsewhere on the board
LED_IN5: RGB.2; also elsewhere on the board

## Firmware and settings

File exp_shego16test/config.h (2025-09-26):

#pragma once

// Rotary encoder - CLK19, DT20, SW21

// RGB Matrix - 15 LEDs (no LED at encoder position [0,3], 10 Ambient LEDs)
#define WS2812_DI_PIN GP22
#define RGB_MATRIX_LED_COUNT 25

// Underglow - 10 ambient LEDs on GP9  
// #define RGBLIGHT_LED_COUNT 10
// #define WS2812_DI_PIN_RGBLIGHT GP9

#define DRIVER_LED_TOTAL 25

// Split configuration
#define WS2812_LED_COUNT_1 15  // Per-key LEDs on GP8
#define WS2812_LED_COUNT_2 10  // Ambient LEDs on GP9

#define MATRIX_ROWS 4
#define MATRIX_COLS 4

// RGB Matrix configuration (for per-key LEDs)

#define RGB_MATRIX_KEYPRESSES
#define RGB_MATRIX_KEYRELEASES
#define RGB_MATRIX_FRAMEBUFFER_EFFECTS

// Underglow configuration
#define RGBLIGHT_EFFECT_BREATHING
#define RGBLIGHT_EFFECT_RAINBOW_MOOD
#define RGBLIGHT_EFFECT_RAINBOW_SWIRL
#define RGBLIGHT_EFFECT_SNAKE
#define RGBLIGHT_EFFECT_KNIGHT
#define RGBLIGHT_EFFECT_CHRISTMAS
#define RGBLIGHT_EFFECT_STATIC_GRADIENT
#define RGBLIGHT_EFFECT_RGB_TEST
#define RGBLIGHT_EFFECT_ALTERNATING
#define RGBLIGHT_EFFECT_TWINKLE

// ST7735 SPI pin configuration (ensure these match your wiring)
#ifndef SPI_SCK
#define SPI_SCK GP2
#endif
#ifndef SPI_MOSI
#define SPI_MOSI GP3
#endif
#ifndef SPI_RES
#define SPI_RES GP4
#endif
#ifndef SPI_DC
#define SPI_DC GP5
#endif
#ifndef SPI_CS
#define SPI_CS GP24
#endif

// Display dimensions (ST7735R 128x128 panel)
#ifndef SPI_WIDTH
#define SPI_WIDTH 128
#endif
#ifndef SPI_HEIGHT
#define SPI_HEIGHT 128
#endif

// Debounce and performance
#define DEBOUNCE 5
#define USB_POLLING_INTERVAL_MS 1

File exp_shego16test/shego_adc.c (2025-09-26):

//shego_adc.c
#include QMK_KEYBOARD_H
#include "quantum.h"
#include "matrix.h"
#include "analog.h"
#include "wait.h"
#include "debug.h"
#include "timer.h"
#include "print.h"

// MUX control pins
#define MUX_S0 GP10
#define MUX_S1 GP11
#define MUX_S2 GP12
#define MUX_S3 GP13
#define MUX1_EN GP14
#define MUX2_EN GP15
#define MUX1_ADC_PIN GP29
#define MUX2_ADC_PIN GP28

// Hall effect thresholds - temporarily lowered for testing
static const uint16_t key_thresholds[32] = {
    // MUX1 thresholds (channels 0-15) - lowered to 400 for testing
    540, 540, 0, 0, 0, 0, 540, 540, 540, 540, 0, 0, 0, 0, 0, 540,
    // MUX2 thresholds (channels 0-15) - lowered to 400 for testing
    540, 540, 0, 0, 0, 0, 540, 540, 540, 540, 0, 0, 0, 0, 540, 540
};

// Map MUX channels to matrix positions
typedef struct {
    uint8_t row;
    uint8_t col;
    uint16_t keycode;
} key_mapping_t;

// MUX1 channel mappings
static const key_mapping_t mux1_keys[16] = {
    {0, 1, KC_2},   // CH0 -> he2 -> "2"
    {0, 0, KC_1},   // CH1 -> he3 -> "1" 
    {255, 255, KC_NO},  // CH2 -> unused
    {255, 255, KC_NO},  // CH3 -> unused
    {255, 255, KC_NO},  // CH4 -> unused
    {255, 255, KC_NO},  // CH5 -> unused
    {1, 0, KC_Q},   // CH6 -> he7 -> "Q"
    {1, 1, KC_W},   // CH7 -> he6 -> "W"
    {1, 2, KC_E},   // CH8 -> he5 -> "E"
    {1, 3, KC_R},   // CH9 -> he4 -> "R"
    {255, 255, KC_NO},  // CH10 -> unused
    {255, 255, KC_NO},  // CH11 -> unused
    {255, 255, KC_NO},  // CH12 -> unused
    {255, 255, KC_NO},  // CH13 -> unused
    {255, 255, KC_NO},  // CH14 -> unused
    {0, 2, KC_3}    // CH15 -> he1 -> "3"
};

// MUX2 channel mappings
static const key_mapping_t mux2_keys[16] = {
    {2, 1, KC_S},   // CH0 -> he10 -> "S"
    {2, 0, KC_A},   // CH1 -> he11 -> "A"
    {255, 255, KC_NO},  // CH2 -> unused
    {255, 255, KC_NO},  // CH3 -> unused
    {255, 255, KC_NO},  // CH4 -> unused
    {255, 255, KC_NO},  // CH5 -> unused
    {3, 0, KC_Z},   // CH6 -> he15 -> "Z"
    {3, 1, KC_X},   // CH7 -> he14 -> "X"
    {3, 2, KC_C},   // CH8 -> he13 -> "C"
    {3, 3, KC_V},   // CH9 -> he12 -> "V"
    {255, 255, KC_NO},  // CH10 -> unused
    {255, 255, KC_NO},  // CH11 -> unused
    {255, 255, KC_NO},  // CH12 -> unused
    {255, 255, KC_NO},  // CH13 -> unused
    {2, 3, KC_F},   // CH14 -> he8 -> "F"
    {2, 2, KC_D}    // CH15 -> he9 -> "D"
};

// Key state tracking
static bool key_pressed[32];
static uint32_t key_timer[32];
static matrix_row_t matrix_state[MATRIX_ROWS];

// SOCD state tracking for A and D keys
static bool a_pressed = false;
static bool d_pressed = false;
static bool a_was_last = false; // Track which was pressed last

// Debug counter to limit output
static uint32_t debug_counter = 0;

#define DEBOUNCE_MS 5
#define HYSTERESIS 20  // Hysteresis to prevent bouncing

// Debug output control
static bool debug_enabled = false;

// Helper for debug printing
#define debug_print(...) do { if (debug_enabled) uprintf(__VA_ARGS__); } while(0)

// Real ADC reading
static uint16_t read_adc_pin(pin_t pin) {
    return analogReadPin(pin);
}

static void select_mux_channel(uint8_t channel) {
    writePin(MUX_S0, (channel & 0x01) ? 1 : 0);
    writePin(MUX_S1, (channel & 0x02) ? 1 : 0);
    writePin(MUX_S2, (channel & 0x04) ? 1 : 0);
    writePin(MUX_S3, (channel & 0x08) ? 1 : 0);
    wait_us(50);
}

void matrix_init_custom(void) {
    // Setup MUX control pins
    setPinOutput(MUX_S0);
    setPinOutput(MUX_S1);
    setPinOutput(MUX_S2);
    setPinOutput(MUX_S3);
    setPinOutput(MUX1_EN);
    setPinOutput(MUX2_EN);
    
    // Disable both MUXes (active low)
    writePinHigh(MUX1_EN);
    writePinHigh(MUX2_EN);
    
    // Initialize ADC pins
    setPinInputHigh(MUX1_ADC_PIN);
    setPinInputHigh(MUX2_ADC_PIN);
    
    // Initialize state
    for (uint8_t i = 0; i < 32; i++) {
        key_pressed[i] = false;
        key_timer[i] = 0;
    }
    
    for (uint8_t row = 0; row < MATRIX_ROWS; row++) {
        matrix_state[row] = 0;
    }
    
}

bool matrix_scan_custom(matrix_row_t current_matrix[]) {
    bool changed = false;
    uint32_t now = timer_read32();
    
    // Clear matrix
    for (uint8_t row = 0; row < MATRIX_ROWS; row++) {
        current_matrix[row] = 0;
    }
    
    // Track raw A and D presses before SOCD cleaning
    bool raw_a_pressed = false;
    bool raw_d_pressed = false;
    
    // Debug output every 2000 scans to reduce spam
    bool debug_this_scan = (debug_enabled && (debug_counter % 2000 == 0));
    if (debug_this_scan) {
        debug_print("\n=== DEBUG SCAN %lu ===\n", debug_counter);
    }

    for (uint8_t ch = 0; ch < 16; ch++) {
        select_mux_channel(ch);
        
        // Read MUX1
        writePinLow(MUX1_EN);   // Enable MUX1
        writePinHigh(MUX2_EN);  // Disable MUX2
        wait_us(100);
        
        uint16_t adc1 = read_adc_pin(MUX1_ADC_PIN);
        uint8_t key_idx1 = ch;
        uint16_t threshold1 = key_thresholds[key_idx1];
        
        // Debug output for active channels
        if (debug_this_scan && threshold1 > 0 && mux1_keys[ch].keycode != KC_NO) {
            debug_print("MUX1 CH%d: ADC=%d, Thresh=%d, Key=%d\n", 
                        ch, adc1, threshold1, mux1_keys[ch].keycode);
        }

        // Process MUX1 key
        if (threshold1 > 0 && mux1_keys[ch].keycode != KC_NO && mux1_keys[ch].row != 255) {
            bool should_press = (adc1 > threshold1);

            // Detect raw A/D
            if (mux1_keys[ch].keycode == KC_A && should_press) raw_a_pressed = true;
            if (mux1_keys[ch].keycode == KC_D && should_press) raw_d_pressed = true;

            // Debug key state changes
            if (debug_this_scan && should_press != key_pressed[key_idx1]) {
                debug_print("MUX1 CH%d Key %d: %s (ADC=%d vs Thresh=%d)\n", 
                            ch, mux1_keys[ch].keycode, 
                            should_press ? "PRESS" : "RELEASE", adc1, threshold1);
            }
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

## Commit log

2025-09-26 Update README with ESP32 GIF player details
    Added information about the ESP32 implementation for the screen.
2025-09-26 Add files via upload
    the SignalRGB plugin for the board
2025-09-26 Add files via upload
    firmware for board
